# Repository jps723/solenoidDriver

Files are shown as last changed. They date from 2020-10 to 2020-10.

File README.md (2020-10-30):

# Solenoid Driver Build Notes 1/26/20

This project is in partnership with [Bantam Tools](https://www.bantamtools.com)

**Design Notes:**

Each 12v solenoid has a 1N4001 diode in parallel with its positive/negative leads, serving as a flyback diode.  The TIP120s serve as switches with signals being directed via an external microcontroller through a 2.2k resistor.

The board is broken up into two sides, with the Arduino signals coming in on one side, and the solenoids being actuated on the other, indicated by an A (Arduino) and an S (Solenoid) in each of the two rows.  External power (12v) enters through a screw terminal on the side of the board.  Polarity is indicated with +/- symbols next to the screw terminals where applicable.  Solenoids are non-polar and so can be oriented any way.  Each Arduino screw terminal port is identical with the exception of one which is required for ground (as indicated by a ‘-‘ symbol).  Arduino signal pins can be any digital pin.

# Build Process
**Bit:** 1/32”
**Mill Time:** <10mins

It’s easiest to solder in this order:
```
1. Resistors
2. Diodes
3. Screw Terminals
4. TIP120s
5. Install heatsinks
```

Test - Sample Code (also within directory)

```
int solenoidPins[] = { 9, 10, 11, 12, 13 };
void setup() {
  setupPins(solenoidPins, 5);
}
void loop() {
  for (int i = 0; i < 5; i++) {
    digitalWrite(solenoidPins[i], HIGH);
	delay(80);
    digitalWrite(solenoidPins[i], LOW);
	delay(80);
  }
}
//set the pins as outputs
void setupPins(int pins[], int lengthOfArray) {
  for (int i = 0; i < lengthOfArray; i++) {
	pinMode(pins[i], OUTPUT);
  }
}
```

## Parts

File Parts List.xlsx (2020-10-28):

Part | Quantity | Notes
Solenoids | 5 | 12v1a
TIP120 Transistors | 5
Screw Terminals | 9 | 1x2, .1" Pitch
2.2k Resistors | 5
1N4001 Diodes | 5

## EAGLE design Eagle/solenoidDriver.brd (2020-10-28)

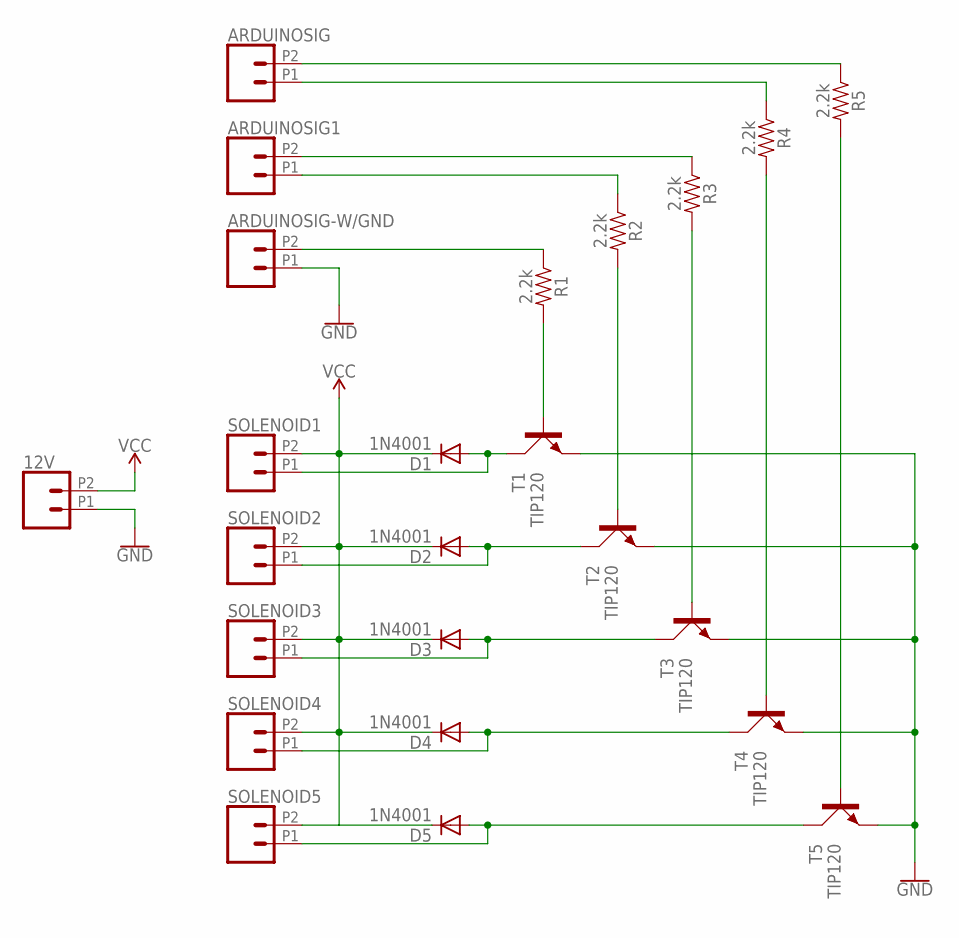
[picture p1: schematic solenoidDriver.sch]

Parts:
12V: CONN_022.54MM_SCREWTERM; 1X02_2.54_SCREWTERM
ARDUINOSIG, ARDUINOSIG1: CONN_022.54MM_SCREWTERM; 1X02_2.54_SCREWTERM
ARDUINOSIG-W/GND: CONN_022.54MM_SCREWTERM; 1X02_2.54_SCREWTERM
D1, D2, D3, D4, D5: 1N4001; DO41-10
R1, R2, R3, R4, R5: 2.2k; AXIAL-0.3-KIT
SOLENOID1, SOLENOID2, SOLENOID3, SOLENOID4, SOLENOID5: CONN_022.54MM_SCREWTERM; 1X02_2.54_SCREWTERM
T1, T2, T3, T4, T5: TIP120; TO220AH-NOHOLE

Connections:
GND: 12V.P1 (1), ARDUINOSIG-W/GND.P1 (1), T1.E, T2.E, T3.E, T4.E, T5.E
unnamed: R1.P$2 (2), T1.B
unnamed: ARDUINOSIG-W/GND.P2 (2), R1.P$1 (1)
unnamed: ARDUINOSIG.P2 (2), R5.P$1 (1)
unnamed: R5.P$2 (2), T5.B
unnamed: ARDUINOSIG.P1 (1), R4.P$1 (1)
unnamed: R4.P$2 (2), T4.B
unnamed: ARDUINOSIG1.P2 (2), R3.P$1 (1)
unnamed: R3.P$2 (2), T3.B
unnamed: ARDUINOSIG1.P1 (1), R2.P$1 (1)
unnamed: R2.P$2 (2), T2.B
unnamed: D2.A, SOLENOID2.P1 (1), T2.C
unnamed: D1.A, SOLENOID1.P1 (1), T1.C
unnamed: D4.A, SOLENOID4.P1 (1), T4.C
unnamed: D3.A, SOLENOID3.P1 (1), T3.C
unnamed: D5.A, SOLENOID5.P1 (1), T5.C
VCC: 12V.P2 (2), D1.C, D2.C, D3.C, D4.C, D5.C, SOLENOID1.P2 (2), SOLENOID2.P2 (2), SOLENOID3.P2 (2), SOLENOID4.P2 (2), SOLENOID5.P2 (2)

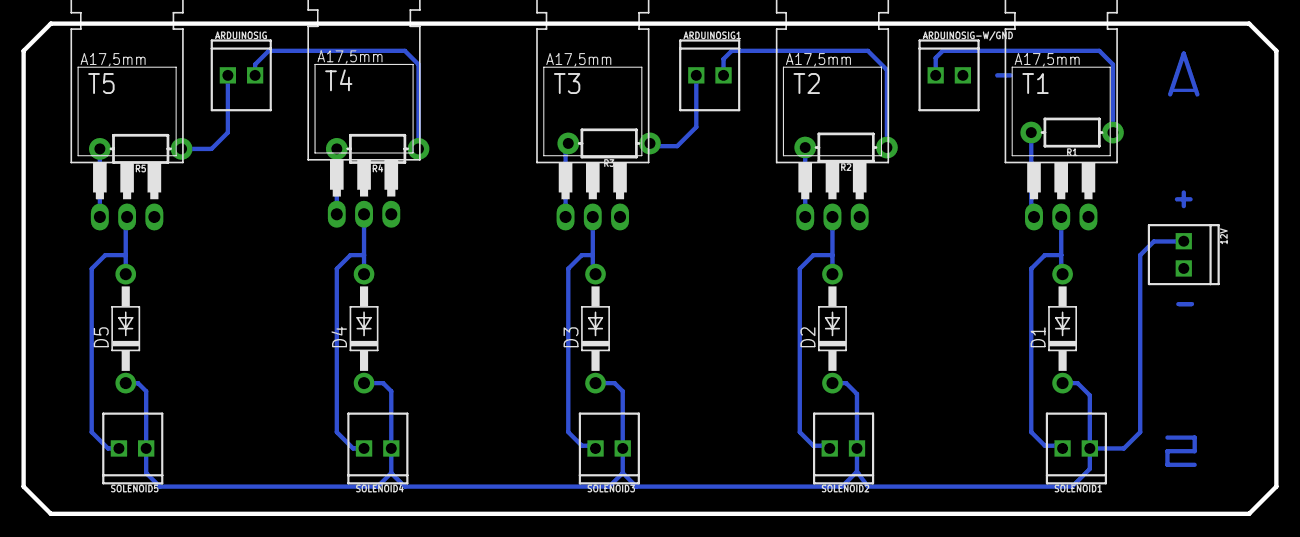
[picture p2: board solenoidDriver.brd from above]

Board: 2 copper layers, 116.8 x 45.7 mm, 24 parts (0 on the bottom side), 17 nets.

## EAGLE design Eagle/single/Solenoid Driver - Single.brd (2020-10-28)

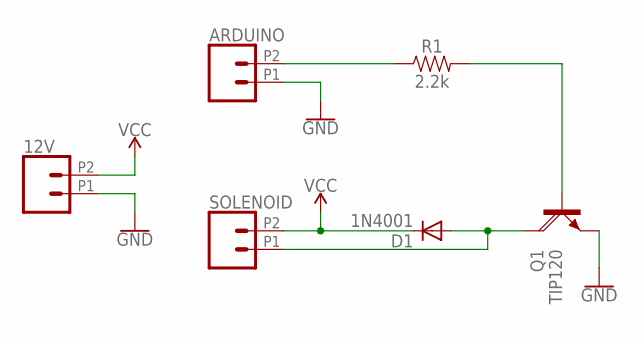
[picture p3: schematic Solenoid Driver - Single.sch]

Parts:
12V: CONN_022.54MM_SCREWTERM; 1X02_2.54_SCREWTERM
ARDUINO: CONN_022.54MM_SCREWTERM; 1X02_2.54_SCREWTERM
D1: 1N4001; DO41-10
Q1: TIP120; TO220AH
R1: 2.2k; AXIAL-0.3-KIT
SOLENOID: CONN_022.54MM_SCREWTERM; 1X02_2.54_SCREWTERM

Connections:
GND: 12V.P1 (1), ARDUINO.P1 (1), Q1.E
unnamed: Q1.B, R1.P$2 (2)
unnamed: ARDUINO.P2 (2), R1.P$1 (1)
unnamed: D1.A, Q1.C, SOLENOID.P1 (1)
VCC: 12V.P2 (2), D1.C, SOLENOID.P2 (2)

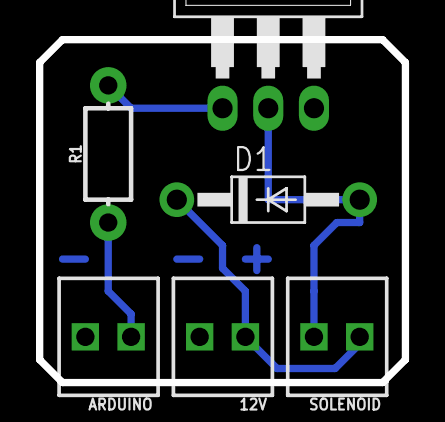
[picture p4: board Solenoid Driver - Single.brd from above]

Board: 2 copper layers, 20.3 x 19.1 mm, 6 parts (0 on the bottom side), 5 nets.

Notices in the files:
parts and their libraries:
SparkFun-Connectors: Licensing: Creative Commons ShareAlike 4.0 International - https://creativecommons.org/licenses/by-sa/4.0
